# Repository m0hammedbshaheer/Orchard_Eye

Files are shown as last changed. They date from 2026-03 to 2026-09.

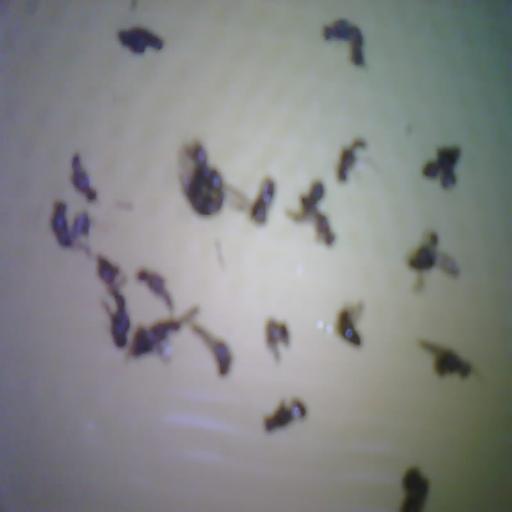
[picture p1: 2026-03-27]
ML_model/Training_databse/test/images/img_20260325_163910_jpg.rf.661747e5282f799f56871a1e923db8b6.jpg

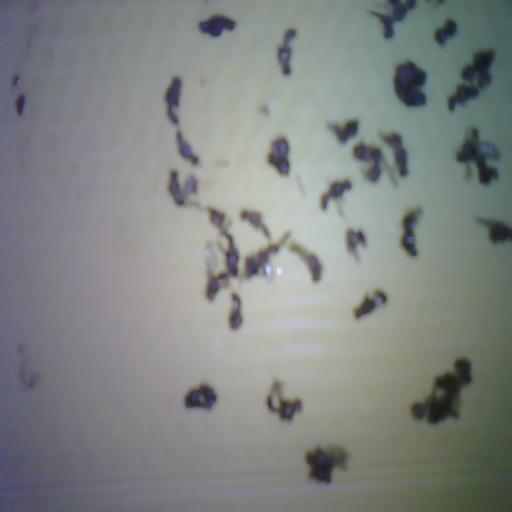
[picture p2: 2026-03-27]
ML_model/Training_databse/test/images/img_20260325_164343_jpg.rf.bfd27d8ebe14a4e8a7f71dfbe8e2e0e1.jpg

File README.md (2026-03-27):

# ArtificialIntelligence-Powered-Pheromone-Trap
Pheromone Trap integrated with IoT devices (Raspberry Pi and ESP-32) and artificial intelligence technology to estimate live count of insects, helping in early detection and estimation of infestation, subsequently helping farmers estimate pesticide spray, preventing pesticide resistance and overuse of pesticides.
# Contributors
Mohammed Shaheer — Embedded Systems & AI Lead. Architected and wired up all the hardware magic — from circuit design to getting the electrons to behave. Also co-developed the computer vision model and handled data augmentation, turning raw trap images into intelligent insect predictions.
Mosin Mushtaq — Full-Stack & IoT Integration Lead. Built the frontend, backend, and engineered the seamless bridge between the ESP32, Raspberry Pi, and the cloud.
# Technology used
microcontrollers and microprocessors:
Esp32 - capture images and send it to cloud server
rapberrypi - download,store and process the data then publish results on the website skuast.store.py
Powersupply: 
5v Battery to give power supple to esp32 which lasts more than 6 months
solar power to extend batterylife
Casing
3D printed custom casing for the project
## AI & Server Workflow
Our implementation handles real-time data flow from capturing images to rendering dynamic analytics.

### Step-by-Step Logic
1. **Image Capture**: The ESP32 triggers the camera, captures the state of the pheromone trap, and sends a `multipart/form-data` POST request to the Raspberry Pi Flask server (`/upload`).
2. **Dynamic Inference**: The Flask Backend catches the image and instantly spins up a customized **YOLOv8** Object Detection Model. The AI scans the image, drawing bounding boxes specifically targeting custom trained classes (Insects, dust, holes).
3. **Difference Calculation**: To ensure we don't double count, the backend (`services/data_service.py`) checks the local `logs.csv` database for the specific trap's last image count. It subtracts the previous count from the current YOLO prediction to find the **hourly difference** (new pests captured).
4. **Data Aggregation**: The new absolute count, image path, timestamp, and difference are physically appended to the system log, preserving historical timeline data without relying on external cloud databases.
5. **Dashboard Visualization**: The image (now overlaid with YOLO bounding boxes) is rendered and saved into the public `/static/img/gallery/` folder where the web-app automatically updates the user dashboard interface with the new live capture and regional trend lines!

### Why YOLOv8 is Preferred
We chose **Ultralytics YOLOv8** over traditional CNN classifiers or cloud APIs because:
* **Edge Optimized**: YOLOv8 is highly optimized for Edge Devices (like Raspberry Pis), performing rapid inferences via CPU without requiring a massive dedicated GPU.
* **Granular Object Detection**: Instead of just outputting "15 bugs", YOLO provides explicit *localization* coordinates, highlighting *where* the bugs actually are. This provides concrete visual proof to farmers navigating the dashboard!
* **Fast Fine-Tuning**: Developing custom classes (filtering out "dust" and "holes" to only focus on actual insects) requires minimal data to achieve state-of-the-art `mAP` metrics.

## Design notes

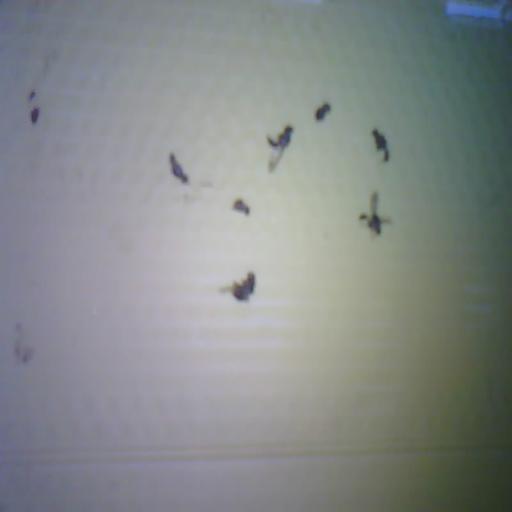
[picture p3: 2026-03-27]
ML_model/Training_databse/valid/images/img_20260325_163100_jpg.rf.ce1524293bd2c194e9c3b48d6708d4d2.jpg

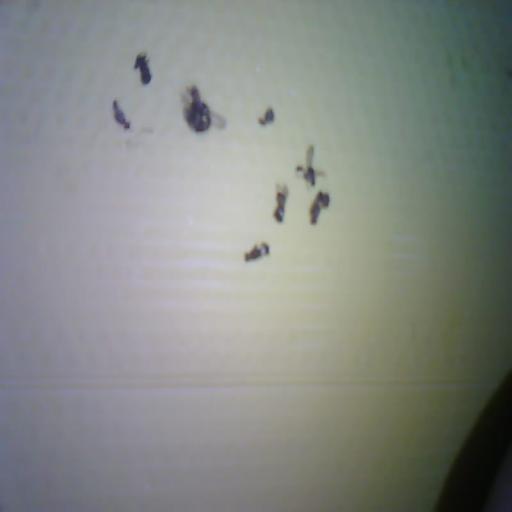
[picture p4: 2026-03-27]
ML_model/Training_databse/valid/images/img_20260325_163427_jpg.rf.0e1ee408f04a52d4c3c075e3cc17a2c5.jpg

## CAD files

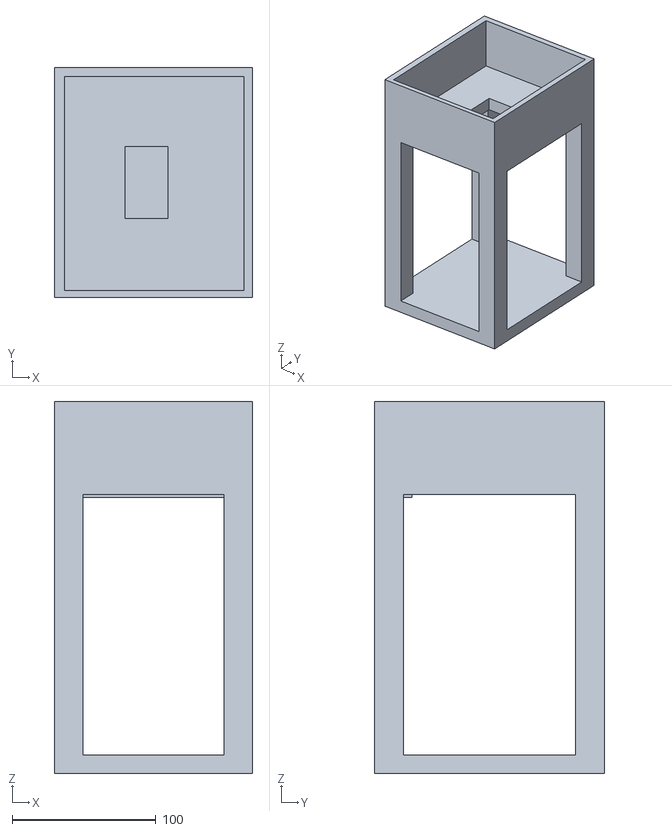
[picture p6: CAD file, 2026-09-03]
Hardware/Casing/reduced.stl
138.0 x 160.0 x 259.0

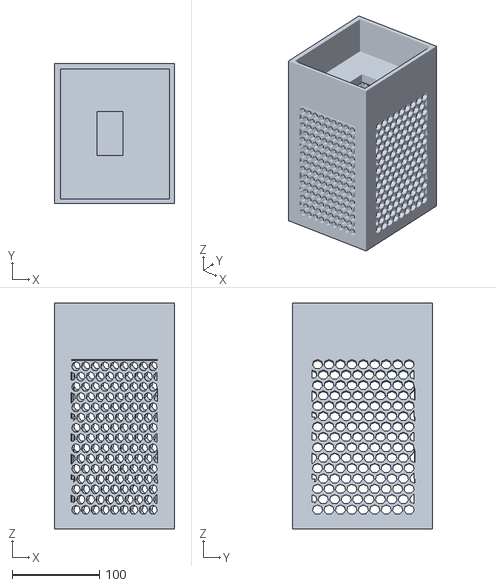
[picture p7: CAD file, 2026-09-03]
Hardware/Casing/honeycomb.stl
138.0 x 160.1 x 259.0

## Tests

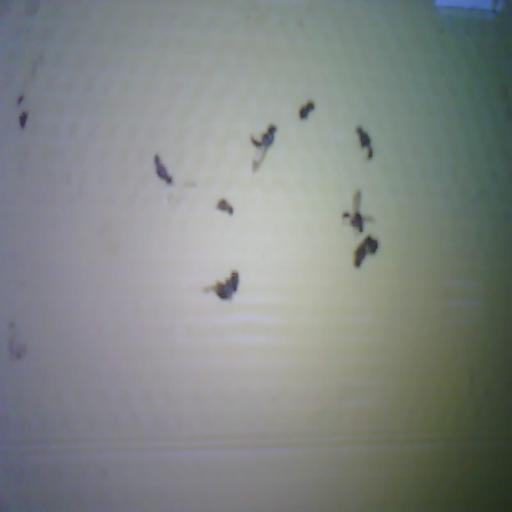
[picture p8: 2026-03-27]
ML_model/Training_databse/test/images/img_20260325_163132_jpg.rf.bd2586f378eecbf387ac72201a71dd29.jpg

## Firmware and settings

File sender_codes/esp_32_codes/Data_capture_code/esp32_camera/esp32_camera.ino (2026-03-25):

// ============================================================
//  ESP32-CAM  →  Laptop HTTP POST
//  WiFi: Pixel_1438
//  Server: 10.242.101.244:5000
// ============================================================

#include "esp_camera.h"
#include <WiFi.h>
#include <HTTPClient.h>

// ---------- CONFIG ----------
#define WIFI_SSID            "Pixel_1438"
#define WIFI_PASS            "tauhapot"
#define SERVER_URL           "http://10.177.13.244:5000/upload"
#define CAPTURE_INTERVAL_MS  10000
// ----------------------------

// ---------- CAMERA PIN MAP (AI-Thinker ESP32-CAM) ----------
#define PWDN_GPIO_NUM     32
#define RESET_GPIO_NUM    -1
#define XCLK_GPIO_NUM      0
#define SIOD_GPIO_NUM     26
#define SIOC_GPIO_NUM     27
#define Y9_GPIO_NUM       35
#define Y8_GPIO_NUM       34
#define Y7_GPIO_NUM       39
#define Y6_GPIO_NUM       36
#define Y5_GPIO_NUM       21
#define Y4_GPIO_NUM       19
#define Y3_GPIO_NUM       18
#define Y2_GPIO_NUM        5
#define VSYNC_GPIO_NUM    25
#define HREF_GPIO_NUM     23
#define PCLK_GPIO_NUM     22
#define LED_GPIO_NUM       4
// -----------------------------------------------------------

#define LOG(msg)        Serial.println(msg)
#define LOGF(fmt, ...)  Serial.printf(fmt "\n", __VA_ARGS__)

// ── LED helpers ─────────────────────────────────────────────
void ledOn()  { digitalWrite(LED_GPIO_NUM, HIGH); }
void ledOff() { digitalWrite(LED_GPIO_NUM, LOW);  }

// ── Camera init ─────────────────────────────────────────────
bool initCamera() {
  camera_config_t config;
  config.ledc_channel = LEDC_CHANNEL_0;
  config.ledc_timer   = LEDC_TIMER_0;
  config.pin_d0       = Y2_GPIO_NUM;
  config.pin_d1       = Y3_GPIO_NUM;
  config.pin_d2       = Y4_GPIO_NUM;
  config.pin_d3       = Y5_GPIO_NUM;
  config.pin_d4       = Y6_GPIO_NUM;
  config.pin_d5       = Y7_GPIO_NUM;
  config.pin_d6       = Y8_GPIO_NUM;
  config.pin_d7       = Y9_GPIO_NUM;
  config.pin_xclk     = XCLK_GPIO_NUM;
  config.pin_pclk     = PCLK_GPIO_NUM;
  config.pin_vsync    = VSYNC_GPIO_NUM;
  config.pin_href     = HREF_GPIO_NUM;
  config.pin_sscb_sda = SIOD_GPIO_NUM;
  config.pin_sscb_scl = SIOC_GPIO_NUM;
  config.pin_pwdn     = PWDN_GPIO_NUM;
  config.pin_reset    = RESET_GPIO_NUM;
  config.xclk_freq_hz = 20000000;
  config.pixel_format = PIXFORMAT_JPEG;

  // Use SVGA for stability — step up to XGA/UXGA only after confirming PSRAM
  config.frame_size   = FRAMESIZE_UXGA;  // 800x600
  config.jpeg_quality = 6;               // 0=best, 63=worst
  config.fb_count     = 1;

  esp_err_t err = esp_camera_init(&config);
  if (err != ESP_OK) {
    LOGF("[CAM][ERROR] Init failed: 0x%x", err);
    return false;
  }
  LOG("[CAM] Camera init OK");
  return true;
}

// ── Capture with warmup ──────────────────────────────────────
camera_fb_t* captureWithWarmup() {
  LOG("[CAM] LED ON – warmup started");
  ledOn();
  delay(5000);
  for (int i = 0; i < 6; i++) {
    camera_fb_t *tmp = esp_camera_fb_get();
    if (tmp) esp_camera_fb_return(tmp);
    delay(120);
  }
  LOG("[CAM] Capturing final frame");
  camera_fb_t *fb = esp_camera_fb_get();
  ledOff();
  LOG("[CAM] LED OFF");
  return fb;
}

// ── WiFi connect ─────────────────────────────────────────────
bool connectWiFi() {
  LOG("[NET] Connecting to WiFi...");
  WiFi.begin(WIFI_SSID, WIFI_PASS);
  WiFi.setSleep(false);
  unsigned long t0 = millis();
  while (WiFi.status() != WL_CONNECTED && millis() - t0 < 15000) {
    delay(500);
    Serial.print(".");
  }
  if (WiFi.status() == WL_CONNECTED) {
    LOG("\n[NET] WiFi connected");
    LOGF("[NET] IP: %s", WiFi.localIP().toString().c_str());
    return true;
  }
  LOG("\n[NET][ERROR] WiFi FAILED");
  return false;
}

// ── HTTP POST image ──────────────────────────────────────────
bool postImage(camera_fb_t *fb) {
  if (!fb) {
    LOG("[HTTP][ERROR] Null frame buffer");
    return false;
  }
  HTTPClient http;
  http.begin(SERVER_URL);
  http.addHeader("Content-Type", "image/jpeg");
  LOGF("[HTTP] POSTing %u bytes to %s", fb->len, SERVER_URL);
  int code = http.POST(fb->buf, fb->len);
  http.end();
  if (code == 200) {
    LOG("[HTTP] Upload OK (200)");
    return true;
  }
  LOGF("[HTTP][ERROR] Response code: %d", code);
  return false;
}

// ── Setup ────────────────────────────────────────────────────
void setup() {
  Serial.begin(115200);
  pinMode(LED_GPIO_NUM, OUTPUT);
  ledOff();

  // PSRAM check
  if (!psramFound()) {
    LOG("[FATAL] No PSRAM detected – halting");
    while (true) delay(1000);
  }
  LOG("[INFO] PSRAM OK");

  if (!initCamera()) {
    LOG("[FATAL] Camera init failed – halting");
    while (true) delay(1000);
  }

  if (!connectWiFi()) {
    LOG("[FATAL] WiFi failed – halting");
    while (true) delay(1000);
  }
}

// ── Loop ─────────────────────────────────────────────────────
void loop() {
  if (WiFi.status() != WL_CONNECTED) {
    LOG("[NET] WiFi lost – reconnecting");
    connectWiFi();
    return;
  }

  camera_fb_t *fb = captureWithWarmup();
  if (fb) {
    postImage(fb);
    esp_camera_fb_return(fb);
  } else {
    LOG("[CAM][ERROR] Capture returned null");
  }

  LOG("[LOOP] Waiting for next capture");
  delay(CAPTURE_INTERVAL_MS);
}

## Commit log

2026-03-18 Added esp32 codes. Final_Project is the deployment code which is later to be deployed and Data_capture is to get rapid data on the trap
2026-03-18 Add ESP32 camera code and laptop server
2026-03-18 managed the low quality photos for testing taken for model training testing, changed the esp32 code to maximum quality
2026-03-25 addming serverside
    [logs.csv]
2026-03-25 adding new esp32 codes
    [partitions.csv]
2026-03-25 changing esp32 to high quality mode
2026-03-27 final touches for 1st prototype
    [results.csv]
2026-06-20 modified: pest_research_data/fields/Field_A/traps/Trap_1/logs.csv modified: pest_research_data/fields/Field_A/traps/Trap_2/logs.csv modified: pest_research_data/fields/Field_A/traps/Trap_3/logs.csv m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
    [logs.csv]
2026-09-03 New file format for better working;
    [honeycomb.stl, logs.csv, reduced.stl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]
2026-09-03 name correction
    [results.csv]
2026-09-03 new plans for the final submission
    [results.csv]
